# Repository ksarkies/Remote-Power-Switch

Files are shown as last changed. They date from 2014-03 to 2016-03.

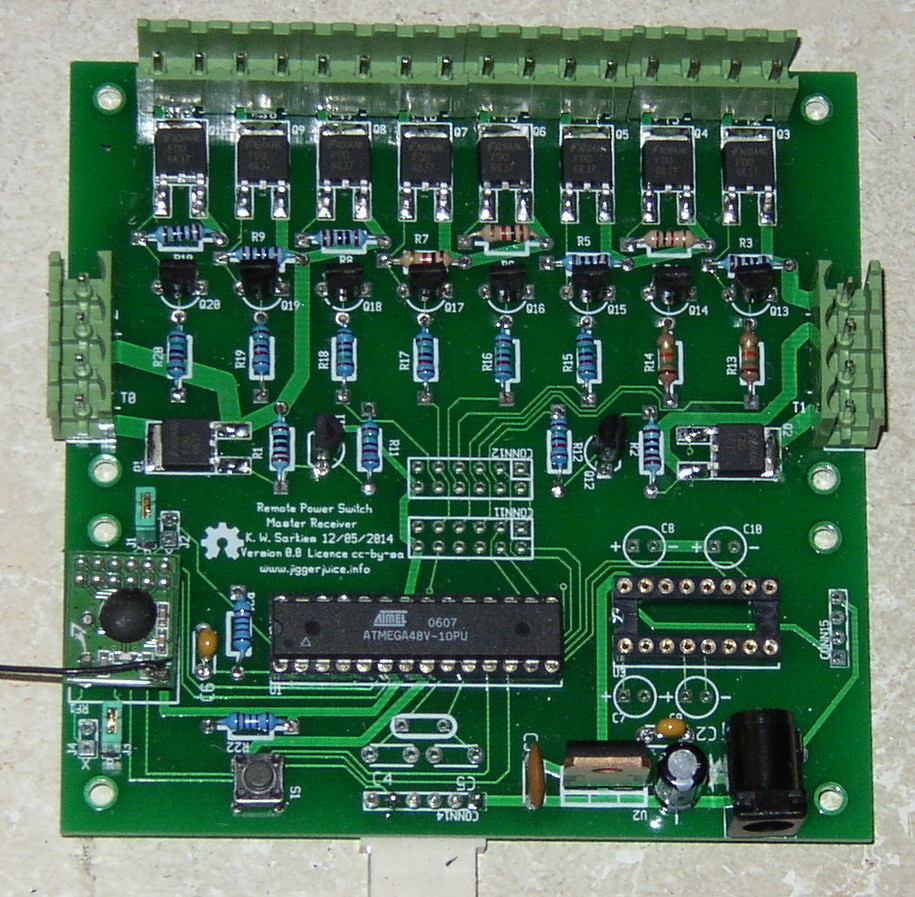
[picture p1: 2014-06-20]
gEDA-master-receiver/master-receiver-photo.jpg

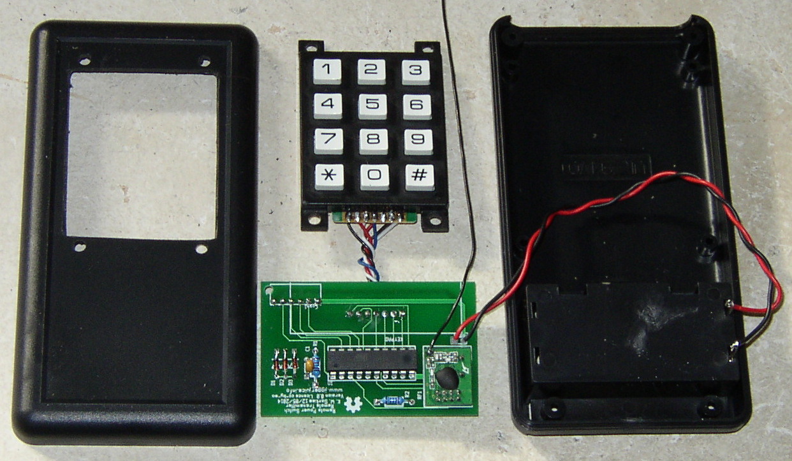
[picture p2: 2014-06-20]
gEDA-remote-transmitter/remote-transmitter-photo.jpg

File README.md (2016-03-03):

Remote Power Switch
-------------------

This small project makes use of Hope RF modules sold by Futurlec and others
to enable remote switching of low voltage power.

(NOTE: These modules seem to be unobtainable. However similar modules such as
the ALPHA-TRX433S, a rebadged version of the 433MHz RFM12B, are available.
The project needs to be redesigned for these and has not been further
developed.)

The background is a 12V power distribution system in a building which is
isolated from the grid and uses solar batteries for all power. The low voltage
used in the system requires care to be taken in regard to losses, so it was
decided to avoid using wall switches which would require additional cable length
with its attendant loss.

A small board uses an RFM02 transmitter module in a hand unit with an Atmel
ATTiny2313. A receiver board using an RFM01 receiver module is mounted at the
power distribution box. While the RF modules supposedly used SPI, the RFM02
modules actually uses a modification of this, meaning that an inbuilt SPI
peripheral on the microcontroller cannot be used. The transmission system is
FM in the 433MHz band.

The system operates by transmitting a single ASCII number continuously when a
button is pressed on the remote unit. The receiver will collect all received
symbols and uses a set of "bins", one for each possible symbol, to hold a
count of the number of each symbol received. A decision is made after 10 symbols
have arrived by selecting the symbol with the most counts. No more decisions are
made until a preset delay has elapsed following the last reception.

More information is available on [Jiggerjuice](www.jiggerjuice.info/electronics/projects/remotecontrol/remote-control-switch.html).

The receiver board is designed to take RFM12 transceiver modules so that the
hardware can double as a serial communications system between two base stations.

More information is available on [Jiggerjuice](www.jiggerjuice.info/electronics/projects/remotecontrol/serial-link-transceiver.html).

K. Sarkies
4 January 2015

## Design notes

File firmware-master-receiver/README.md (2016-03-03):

Remote Power Switch Rx Firmware
-------------------------------

The unit enters sleep mode until woken by a received character or the timer.
It collects all received characters, filters out invalid characters, and counts
instances of each valid character. After 10 valid characters have been received,
the character with the highest count is considered to be the correct
transmission. This is a form of maximum likelihood estimator.

The ATMega48 AVR microcontroller must have 8MHz internal RC oscillator and
no other fuse bits set except for the serial programming enable.

More information has been posted on [Jiggerjuice](www.jiggerjuice.info/electronics/projects/remotecontrol/remote-control-switch.html).

K. Sarkies

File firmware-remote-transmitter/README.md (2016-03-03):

Remote Power Switch Tx Firmware
-------------------------------

The unit enters sleep mode until a keyboard interrupt occurs. It then scans
the keys to determine which one was pressed. Debounce is performed, then the
digit is transmitted via the RFM02 module. This process continues as long
as the key is pressed.

The clock of the ATTiny2313 must be set to internal calibrated 8MHz. The clock
divide by 8 must be unset.

More information has been posted on [Jiggerjuice](www.jiggerjuice.info/electronics/projects/remotecontrol/remote-control-switch.html).

K. Sarkies

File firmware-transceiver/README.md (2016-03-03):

Remote Power Switch Transceiver Firmware
----------------------------------------

The Transceiver unit provides a serial link with input and output at RS232 or
logic levels.

The serial bit rate at both ends of the link needs to be the same as that set in
the firmware. This can be changed by recompiling the firmware. The transceiver
can handle bursts up to the length of the serial buffers. These are made larger
for AVRs with larger RAM.

The throughput of the unit is restricted by buffer size and AVR speed. A large
amount of serial data sent in a burst can result in loss.

The AVR C library rfm12lib by Hansinator, Tixiv and Soeren provides the software
support for the RFM12 modules. The interrupt driven UART library developed by
Peter Fleury is also used.

More information is found on [Jiggerjuice](www.jiggerjuice.info/electronics/projects/remotecontrol/serial-link-transceiver.html).

The ATMega48 series is used. The USART buffer sizes are:
ATMega48    128
ATMega88    256
ATMega168   256
ATMega328   1024

K. Sarkies
20 April 2015

TODO: Add sleep modes for AVR and RFM12 after 10 seconds inactivity. Wake on
      USART and INT0.

TODO: Attempts were made to improve throughput, without success, for use with
the Battery Management System. A request for a long directory listing results
in the latter losing characters. Sending the BMS general data at low priority
and the directory listing at high priority made no difference. The most
likely explanation is the limited buffering available in the transceiver AVR.

Some improvements would be:
- Add USART flow control.
- Change the transceiver SCP interactions to hardware rather than software.

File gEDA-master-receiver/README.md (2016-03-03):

Remote Power Switch Rx PCB
--------------------------

This board has a dual purpose; serving as a receiver for the power switch and as
an RF to serial converter. The board is designed to allow cutting to separate
the microcontroller and the switch parts. Provision for a ribbon cable
connection between the two is given so that boards may be interchanged with
different types. This is compatible with the ET-REL8BRD 8 relay board, and
possibly others. It uses an Atmel microcontroller and a RFM01 Hope RF 433MHz FM
receiver. The alternate configuration takes an RFM12 transceiver with different
jumper settings. The RFM01 Receiver configuration uses jumpers labelled R, while
the RFM12 Transceiver uses configuration jumpers labelled X.

The switches are P-type MOSFETs with low speed BJT-resistor drivers for
simplicity. The microcontroller is a low cost ATMega48 or pin compatible
ATMEL device with provision for a crystal oscillator if needed. The serial
interface is provided by a MAX232 RS-232 driver, although the serial interface
could be simple logic level if desired by omitting the MAX232 and jumpering
between its input and output pins. The serial connector is a SIL header
compatible with the ET series of boards. An SPI programming connector is also
provided in a form compatible with other projects. The vertical version of this
(or the right angle version mounted underneath) must be used.

More information has been posted on [Jiggerjuice](www.jiggerjuice.info/electronics/projects/remotecontrol/remote-control-switch.html).

K. Sarkies

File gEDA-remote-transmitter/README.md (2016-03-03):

Remote Power Switch Tx PCB
--------------------------

This board is designed to fit into a 65mm by 130mm hand case, purchased from
Jaycar, with a 12 digit keypad. It has an Atmel microcontroller in sleep mode
that is woken up when a keypress is activated. An RFM02 Hope RF 433MHz
transmitter unit is also in sleep mode until needed.

The keypad is of unknown manufacturer, supplied by Futurlec. It has a 7 pin
connector underneath, below the top row of buttons. The board will 
need to be redesigned to suit other keypads, taking care about physical
mounting. This keypad can be mounted underneath the board and facing so that
the board partly covers it, or ir could be mounted on top of the board facing
the opposite direction if it is mounted high enough for other components to be
mounted underneath it. The right-angle SPI connector can be mounted on top of
the board under the keypad, or underneath facing in the opposite direction.
Space constraints require the RF board to sit partly underneath the keypad.

The aerial for the RF board needs to be 173mm which is longer than the case. To
provide an efficient aerial it is made up of a 120mm length of wire with 6
turns wound over a 0.25W resistor (acting purely as a former) to make a bottom
loaded quarter wave aerial.

The row and column ports are set with the rows having high-level pullup and the
columns set to zero. A connection between any row and column will then result
in the interrupt line being pulled low via the diode network.

The prototype units have survived for over 12 months without a change of
batteries.

More information has been posted on [Jiggerjuice](www.jiggerjuice.info/electronics/projects/remotecontrol/remote-control-switch.html).

K. Sarkies
30 May 2014

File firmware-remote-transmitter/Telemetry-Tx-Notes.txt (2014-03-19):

    /* Configuration Setting: 433MHz, CLK 5MHz, 11,5pf Kapaz., +/-60kHz */
    sendbyte(0b10001110);    sendbyte(0b01100000); 
0x8E60
    /* Frequency Setting: eingestellter Kanal*/
    uc_frequ[1]|=0b10100000;
0xA0xx
    /* Output Power Command: Max Power */
    sendbyte(0b10110000);
0xB0
    /* Data Rate Command: 2400 bit/s */
    sendbyte(0b11001000);    sendbyte(0b10001111); 
0xC88F
    /* Low Batt + Sync Command: enable Sync Circuit */
    sendbyte(0b11000010);    sendbyte(0b00100000); 
0xC220
    /* PLL Setting Command: 0xD240 up to 19,2kbit/s*/
    sendbyte(0b11010010);    sendbyte(0b01000000); 
0xD240
    /* Power Managment Command= Enable Clock; disable Synthesizer; disable pow. Ampl. */
    sendbyte(0b11000000);    sendbyte(0b00100000); 
0xC020

Main program checks for new values, sends them, and reinitializes the entire Tx chain if the transmission takes too long to complete.

    /* Power Managment Command= Enable Clock; enable Synthesizer; enable pow. Ampl. */
    sendbyte(0b11000000);    sendbyte(0b00111000); 
0xC034
    /*Sender Start Byte senden*/
    sendbyte(0b11000110);
0xC6

He appears to start transmission immediately after turning on the Synthesizer, which normally needs 250uS. The clock is already on.

Transmission of data is sent one bit at a time and paced by interrupt (on INT0 from nIRQ presumably).

    /* Power Managment Command= Enable Clock; disable Synthesizer; disable pow. Ampl. */
    sendbyte(0b11000000);    sendbyte(0b00100000); 
0xC020
--------------------------------------------------------------------------------------------------------------------------
Rx
    /* Frequency Setting: 434MHz (je nach Kanal) */
    uc_frequ[1]|=0b10100000;
0xA015
    
    /* Configuration Setting: 433MHz, CLK on, 11,5pf Kapaz., 67kHz */
    sendbyte(0b10001001);    sendbyte(0b01101100); 
0x8A6C
    
    /* Low Batt Clock Divider Command: clock 5MHz */
    sendbyte(0b11000010);    sendbyte(0b11000000); 
0xC2C0
    
    /* Receiver Setting Command: VDI= Digital RSSI Out, -103dB, receiver disabled */
    sendbyte(0b11000000);    sendbyte(0b10000000);
0xC080
    
    /* Receiver Setting Command: VDI= Digital RSSI Out, -103dB receiver enabled */
    sendbyte(0b11000000);    sendbyte(0b10000001);
0xC081
       
    /* FIFO Command: Enable FIFO, IT level=8, Sync. Patt + VDI, stop FIFO  */
    sendbyte(0b11001110);    sendbyte(0b10001001);
0xCE89
    
    /* FIFO Command: Enable FIFO, IT level=8, Sync. Patt + VDI, start FIFO  */
    sendbyte(0b11001110);    sendbyte(0b10001011);
0xCE8B
    
    /* Data Filter Command:  */
    sendbyte(0b11000100);    sendbyte(0b10101100); 
0xC4AC    
    
    /* Data Rate Command: 2400 bit/s */
    sendbyte(0b11001000);    sendbyte(0b10010001);
0xC891    
    
    /* AFC Command: Enable AFC, +3/-4, offset at VDI high */
    sendbyte(0b11000110);    sendbyte(0b10111111); 
0xC6BF

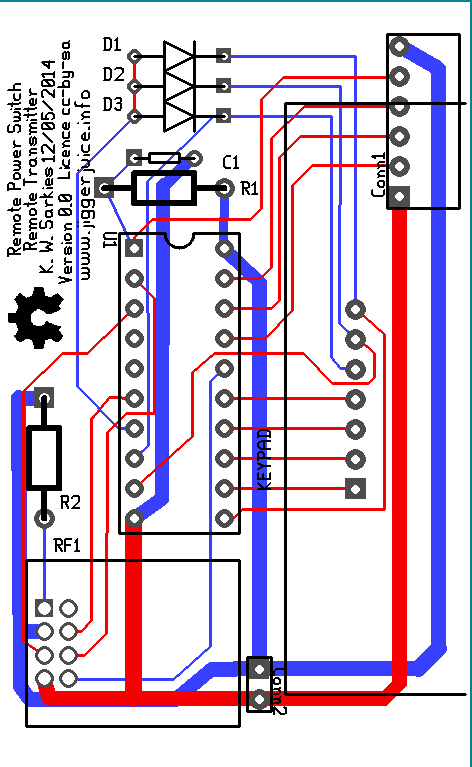
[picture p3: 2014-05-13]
gEDA-remote-transmitter/remote-transmitter-pcb-v1.png

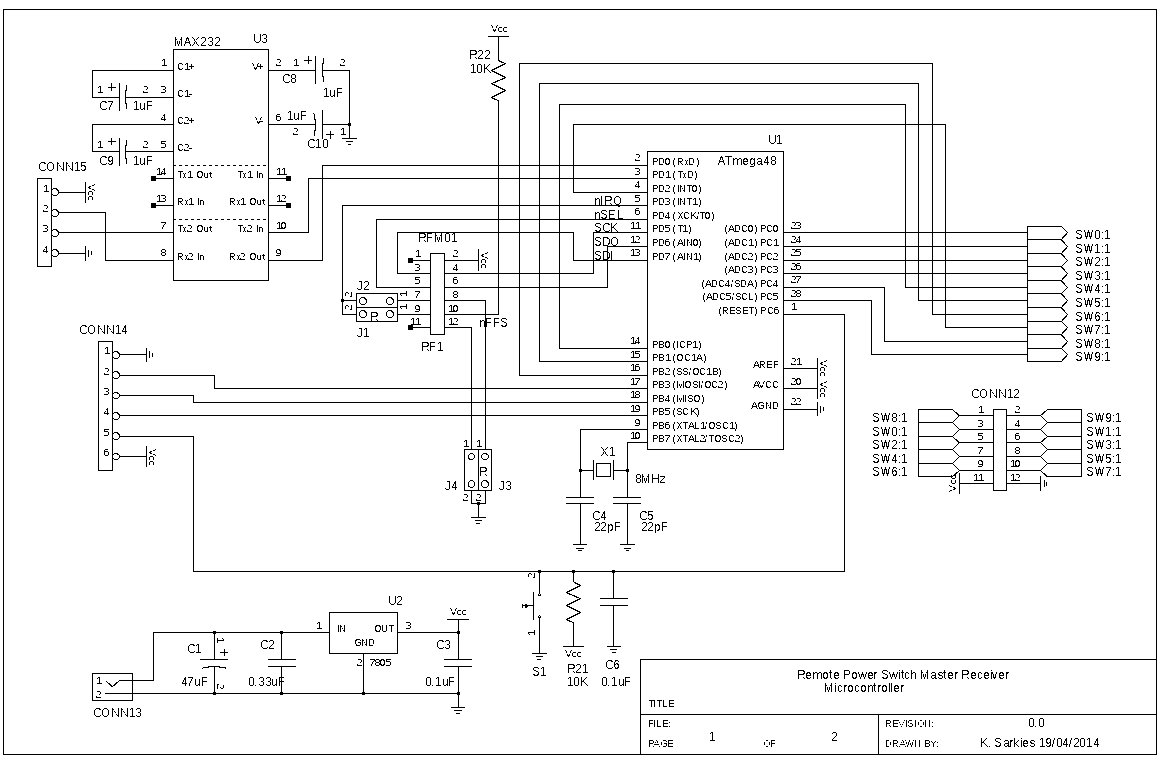
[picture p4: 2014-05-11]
gEDA-master-receiver/master-receiver-mc.png

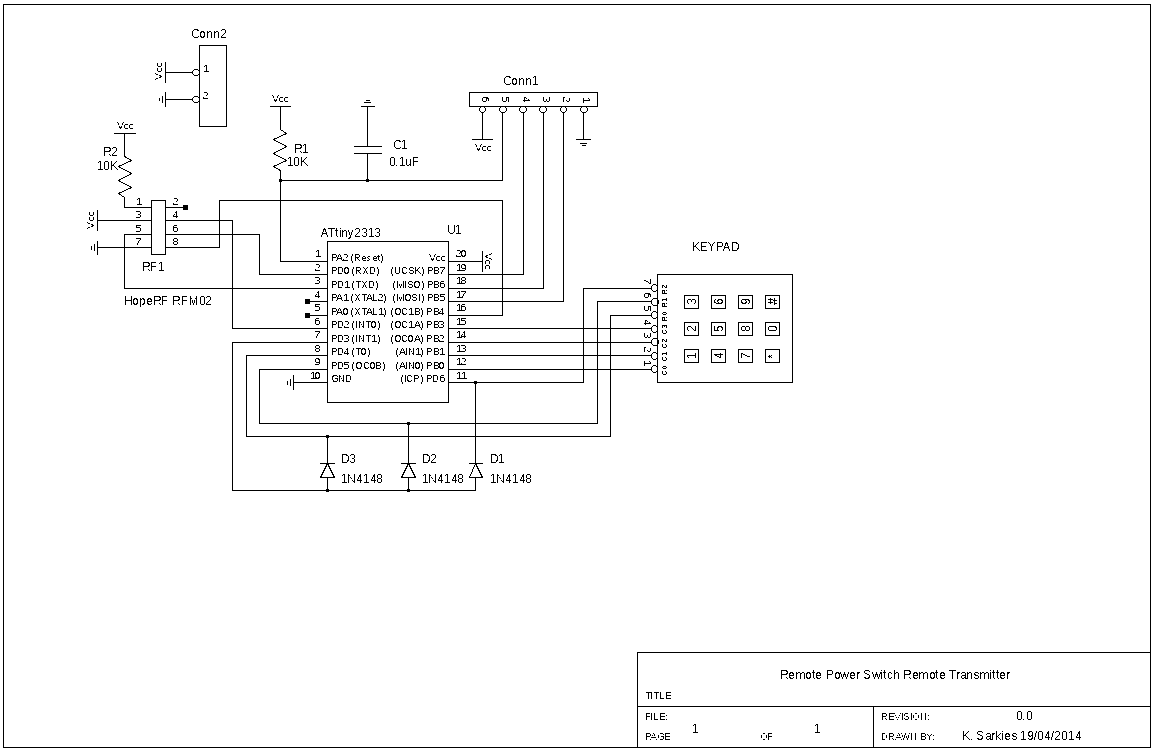
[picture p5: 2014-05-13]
gEDA-remote-transmitter/remote-transmitter.png

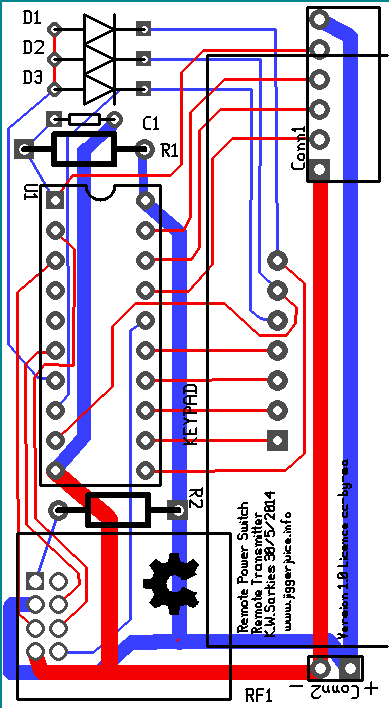
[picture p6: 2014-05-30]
gEDA-remote-transmitter/remote-transmitter-pcb.png

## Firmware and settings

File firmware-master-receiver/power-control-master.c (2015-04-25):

/**
@mainpage Power Control Project Master Unit
@version 0.0.0
@author Ken Sarkies (www.jiggerjuice.net)
@date 25 April 2015
@brief Code for a Master Power Switch unit

*** This sets the sleep mode, and requires the 8-bit timer 0 to generate
*** a timing tick.

This is a project to control power remotely using a wireless connection
between remote control units and a master switch unit. The master switch
board will interface to an ET-REL8 relay board using a 10 pin connector.
Each relay is activated by a separate port pin. It also interfaces to a
Hope RFM01 433MHz receiver module.

In principle the Master Power Switch units can be used for a wide range of
purposes as they simply receive command bytes over a serial link interface.
The interface used is the SPI interface to match the radio receiver module
RFM01. Other interfaces could simply be substituted.

The protocol used needs to match the sync pattern of the RF receiver:

AA AA AA 2D D4 ...

@note
Software: AVR-GCC 3.4.5
@note
Target:   Any AVR with sufficient output ports and a timer
@note
Tested:   ATMega48 at 8MHz internal clock.
 */
/***************************************************************************
 *   Copyright (C) 2011 by Ken Sarkies                                     *
 *   ksarkies@internode.on.net                                             *
 *                                                                         *
 *   This file is part of Power Controller                                 *
 *                                                                         *
 *   This is free software; you can redistribute it and/or modify          *
 *   it under the terms of the GNU General Public License as published by  *
 *   the Free Software Foundation; either version 2 of the License, or     *
 *   (at your option) any later version.                                   *
 *                                                                         *
 *   This software is distributed in the hope that it will be useful,      *
 *   but WITHOUT ANY WARRANTY; without even the implied warranty of        *
 *   MERCHANTABILITY or FITNESS FOR A PARTICULAR PURPOSE.  See the         *
 *   GNU General Public License for more details.                          *
 *                                                                         *
 *   You should have received a copy of the GNU General Public License     *
 *   along with the software. If not, write to the:                        *
 *   Free Software Foundation, Inc.,                                       *
 *   51 Franklin St, Fifth Floor, Boston, MA  02110-1301  USA.             *
 ***************************************************************************/

#include <inttypes.h>
#include <avr/sfr_defs.h>
#include <avr/wdt.h>
#include <avr/io.h>
#include <avr/interrupt.h>
#include <avr/sleep.h>
#include <util/delay.h>
#include "power-control-master.h"
#include "../libs-master-receiver/power-control-atmega48.h"
#include "../libs-master-receiver/rfm01.h"
/* Need to include source file here to access defines referred to above */
#include "../libs-master-receiver/rfm01.c"

/** Convenience macros (we don't use them all) */
#define TRUE 1
#define FALSE 0

#define inb(sfr) _SFR_BYTE(sfr)
#define inw(sfr) _SFR_WORD(sfr)
#define outb(sfr, val) (_SFR_BYTE(sfr) = (val))
#define outw(sfr, val) (_SFR_WORD(sfr) = (val))
#define cbi(sfr, bit) (_SFR_BYTE(sfr) &= ~_BV(bit))
#define sbi(sfr, bit) (_SFR_BYTE(sfr) |= _BV(bit))
#define high(x) ((uint8_t) (x >> 8) & 0xFF)
#define low(x) ((uint8_t) (x & 0xFF))

/*****************************************************************************/
/* Global Variables */

/** Set of 12 byte bins to count data received values. These will be used to
determine the median data value after a number of valid receives. */
uint8_t dataCount[12];
/** Real Time Clock Global Variable, ticks are 30.5 per second */
uint32_t timeValue;

/*****************************************************************************/
/* Local Prototypes */

void hardwareInit(void);
void wdtInit(void);
void snooze(void);
void setSwitch(uint8_t bestData);
void clearSwitches(void);
void resetTimer(void);
/*****************************************************************************/
/** @brief Main Program */

int main(void)
{
    hardwareInit();                 /* Initialize the processor specific hardware */
    resetTimer();                   /* Configure the timer */
    timeValue = 0;                  /* reset timer */
    initSPI();
    receiverConfigure();            /* Initialize the receiver */
    uint8_t data = 0;
    uint8_t invalidData = 0;
    uint8_t validData = 0;
    uint8_t locked = FALSE;
    for (uint8_t bin=0; bin < 12; bin++) dataCount[bin] = 0;

/** The main loop will check for symbols received. This is tested for
validity and counted in bins to determine the median value as a best
estimate. Then the data is interpreted to toggle one of a number of ports
or perform other actions. The system is then locked to prevent any further
interpretations until a period of 2 seconds has elapsed following the last
valid received symbol. */

    for(;;)
    {
/** The processor sleeps until woken by a received byte or a timer tick */
        snooze();
	    uint16_t receiverStatus = readDataByte();
/** The MSB of the status word is tested as FFIT. */
        if ((receiverStatus & 0x8000) != 0)    /* Check if something received */
        {
/** If nothing has been received for 2 seconds, release and clear the system to
allow other control commands to be activated. */
            if (timeValue > 61)
            {
                locked = FALSE;
                invalidData = 0;
                validData = 0;
                for (uint8_t bin=0; bin < 12; bin++) dataCount[bin] = 0;
            }
            resetTimer();
            timeValue = 0;                  /* reset timer */
            data = low(receiverStatus);
            resetFIFO();
/** When data is received, check if it is valid and increment its bin */
            if ((data < 12) && !locked)
            {
                dataCount[data]++;
                validData++;
            }
            else invalidData++;
/** Wait for 10 valid received data and then check the bins */
            if (validData == 10)
            {
                locked = TRUE;              /* prevent more recognitions */
                validData = 0;              /* prevent returning here while locked */
/** Look through bins and find the location of the peak (will return first equal peak) */
                uint8_t maxData = 0;
                uint8_t bestData = 0;
                for (uint8_t i=0; i<12; i++)
                {
                    if (dataCount[i] > maxData)
                    {
                        maxData = dataCount[i];
                        bestData = i;
                    }
                }
/** With the estimated data value, set the appropriate port. Toggle the
existing value of the port. */
                if (bestData < 10) setSwitch(bestData);
/** Use the remaining four symbols for general controls */
/* Turn off all ports */
                else if (bestData == 11) clearSwitches();
            }
        }
    }
}

/****************************************************************************/
/** @brief Initialize the hardware.
*/
void hardwareInit(void)
{
/** Power down Timers 0 and 1, TWI, SPI, ADC and USART */
    outb(PRR,0xBF);
/** We use Interrupt 1 with level triggering for power save mode */
    sbi(EIMSK,INT1);                /* Enable Interrupt 1 */
    cbi(EICRA,ISC11);               /* Set level trigger on interrupt 1 */
    cbi(EICRA,ISC10);
/** Set control ports as outputs */
    outb(DDRC,inb(DDRC) | 0x3F);
    outb(DDRB,inb(DDRB) | 0x07);
    outb(DDRD,inb(DDRD) | 0x04);
    sei();                          /* Enable global interrupts */
}

/****************************************************************************/
/** @brief   Initialise Timer 2

This function will initialise the timer with the mode of operation and the
clock rate to be used.
*/

void resetTimer(void)
{
/** Set timer to FCPU/1024 which is about 30.5 overflows per second for 8MHz. */
    outb(TIMER_CONT_REG,((inb(TIMER_CONT_REG) & 0xF8) | 5));
    outb(TCOUNT,0);              /* Clear the register */
    sbi(TIMER_FLAG_REG, TOV);    /* Force clear the overflow interrupt flag */
    sbi(TIMER_MASK_REG, TOIE);   /* Enable the overflow interrupt */
}

/****************************************************************************/
/** @brief Initialize the watchdog timer to interrupt on maximum delay

*/
void wdtInit(void)
{
/* Initialize the Watchdog timer to interrupt. */
/* IMPORTANT: Disable the "WDT Always On" fuse so that WDT can be turned off. */
    wdt_disable();     /* watchdog timer turn off ready for setup. */
    outb(WDTCR,0);
/* Set the WDT with WDE clear, interrupts enabled, interrupt mode set, and
maximum timeout 8 seconds to give continuous interrupt mode. */
    sei();
}

/****************************************************************************/
/** @brief Send processor to sleep and manage interrupts.

This function is called at the beginning of every processing loop. The INT1
is enabled before sleeping, and disabled after wakeup.
*/
void snooze(void)
{
    sei();                              /* Enable global interrupts */
    sbi(EIMSK,INT1);                    /* Enable Interrupt 1 */
    set_sleep_mode(SLEEP_MODE_PWR_SAVE);
    sleep_mode();                       /* Enter sleep mode */
    cbi(EIMSK,INT1);                    /* Disable Interrupt 1 */
}

/****************************************************************************/
/** @brief Manage the power switching.

Adapt the switches 0-9 to the actual microcontroller port outputs.

@param[in] uint8_t bestData. The number of the switch to toggle.
*/
void setSwitch(uint8_t bestData)
{
    uint16_t bestBit = (1 << bestData);
/* The lower 4 bits of PORTC are the first four ports */
    if (bestData < 4) outb(PORTC,inb(PORTC) ^ bestBit);
/* The lower 3 bits of PORTB are the next three ports */
    else if (bestData < 7) outb(PORTB,inb(PORTB) ^ (bestBit >> 4));
/* Bit 2 of PORTD is the eighth port */
    else if (bestData == 7) outb(PORTD,inb(PORTD) ^ 4);
/* Bits 4,5 of PORTC are the ninth and tenth ports */
    else if (bestData < 10) outb(PORTC,inb(PORTC) ^ (bestBit >> 4));
}

/****************************************************************************/
/** @brief Turn off all power switching.
*/
void clearSwitches(void)
{
    outb(PORTC,(inb(PORTC) & ~0x3F));
    outb(PORTB,(inb(PORTB) & ~0x07));
    outb(PORTD,(inb(PORTD) & ~0x04));
}
/****************************************************************************/
/** @brief Interrupt on nIRQ from Receiver.

This ISR does nothing except to allow the processor to wakeup.
*/
ISR(REC_INTERRUPT)
{
}

/****************************************************************************/
/** @brief Interrupt on RTC timer overflow

This ISR simply updates the RTC.
*/
ISR(TIMER_INTERRUPT)
{
  timeValue++;
}

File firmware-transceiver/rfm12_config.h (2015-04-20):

/**** RFM 12 library for Atmel AVR Microcontrollers *******
 * 
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
 * @author Peter Fuhrmann, Hans-Gert Dahmen, Soeren Heisrath
 */

#ifndef _RFM12LIB_H_
#define _RFM12LIB_H_

/******************************************************
 *                                                    *
 *           C O N F I G U R A T I O N                *
 *                                                    *
 ******************************************************/

/*
	Connect the RFM12 to the AVR as follows:

	RFM12           | AVR
	----------------+------------
	SDO             | MISO
	nIRQ            | INT0
	FSK/DATA/nFFS   | VCC
	DCLK/CFIL/FFIT  |  -
	CLK             |  -
	nRES            |  -
	GND             | GND
	ANT             |  -
	VDD             | VCC
	GND             | GND
	nINT/VDI        | -
	SDI             | MOSI
	SCK             | SCK
	nSEL            | Slave select pin defined below
*/


/************************
 * PIN DEFINITIONS
 */

/*Pin that the RFM12's slave select is connected to */
#define DDR_SS DDRD
#define PORT_SS PORTD
#define BIT_SS 4

/* Using Software SPI */
/*SPI MOSI port */
#define DDR_MOSI DDRD
#define PORT_MOSI PORTD

/*SPI MISO port */
#define DDR_MISO DDRD
#define PIN_MISO PIND

/*SPI SCK port */
#define DDR_SCK DDRD
#define PORT_SCK PORTD

/*SPI SS port */
#define DDR_SPI_SS DDRD
#define PORT_SPI_SS PORTD 

/*SPI pin numbers on their respective ports */
#define BIT_MOSI 7
#define BIT_MISO 6
#define BIT_SCK  5
#define BIT_SPI_SS 4

/************************
 * RFM12 CONFIGURATION OPTIONS
 */

//baseband of the module (either RFM12_BAND_433, RFM12_BAND_868 or RFM12_BAND_912)
#define RFM12_BASEBAND RFM12_BAND_433

//center frequency to use (+-125kHz FSK frequency shift)
#define FREQ 433175000UL

//use this for datarates >= 2700 Baud
#define DATARATE_VALUE RFM12_DATARATE_CALC_HIGH(38400.0)

//use this for 340 Baud < datarate < 2700 Baud
//#define DATARATE_VALUE RFM12_DATARATE_CALC_LOW(1200.0)

//TX BUFFER SIZE
#ifndef RFM12_TX_BUFFER_SIZE
#define RFM12_TX_BUFFER_SIZE 30
#endif

//RX BUFFER SIZE (there are going to be 2 Buffers of this size for double_buffering)
#ifndef RFM12_RX_BUFFER_SIZE
#define RFM12_RX_BUFFER_SIZE 30
#endif


/************************
 * INTERRUPT VECTOR
 * set the name for the interrupt vector here
 */
 
//the interrupt vector
#define RFM12_INT_VECT (INT1_vect)

//the interrupt mask register
#define RFM12_INT_MSK EIMSK

//the interrupt bit in the mask register
#define RFM12_INT_BIT (INT1)

//the interrupt flag register
#define RFM12_INT_FLAG EIFR

//the interrupt bit in the flag register
#define RFM12_FLAG_BIT (INTF1)

//setup the interrupt to trigger on negative edge
#define RFM12_INT_SETUP()   EICRA |= (1<<ISC11)


/************************
 * FEATURE CONFIGURATION
 */

#define RFM12_LIVECTRL 0
#define RFM12_NORETURNS 0
#define RFM12_NOCOLLISIONDETECTION 0
#define RFM12_TRANSMIT_ONLY 0
#define RFM12_SPI_SOFTWARE 1
#define RFM12_USE_POLLING 0
#define RFM12_RECEIVE_ASK 0
#define RFM12_TRANSMIT_ASK 0
#define RFM12_USE_WAKEUP_TIMER 0
#define RFM12_LOW_POWER 0


/************************
 * UART DEBUGGING
 * en- or disable debugging via uart.
 */
 
#define RFM12_UART_DEBUG 0

#endif

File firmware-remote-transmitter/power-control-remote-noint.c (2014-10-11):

/**
@mainpage Power Control Project Remote Unit on AVR
@version 0.0.0
@author Ken Sarkies (www.jiggerjuice.info)
@date 06/06/2011
@brief Test code for a Remote Power Switch unit on AVR

Based on code by:
 * (C) 2009 by Tomasz bla Fortuna <bla@thera.be>.
 * http://olek.tk/en/rfm12.php
 * License: GPLv3+ (See Docs/LICENSE)

This is a project to control power remotely using a wireless connection
between remote control units and a master switch unit.

In principle the remote control units can be used for a wide range of
purposes as they simply send keyboard command bytes from keypresses
over a serial link interface. The interface used is the SPI interface to
match the radio transmitter module Hope RFM02. Other interfaces could simply
be substituted.

The protocol used needs to match the sync pattern of the RF receiver, but
otherwise the packets will have the same structure as that for the acquisition
project. The sync pattern is:

AA AA AA 2D D4 ...

@note
Software: AVR-GCC 3.4.5
@note
Target:   Any AVR
@note
Tested:   ATMega48, ATTiny2313 at 8MHz internal clock.
 */
/***************************************************************************
 *   Copyright (C) 2010 by Ken Sarkies                                     *
 *   ksarkies@internode.on.net                                             *
 *                                                                         *
 *   This file is part of Power Controller                                 *
 *                                                                         *
 *   This is free software; you can redistribute it and/or modify          *
 *   it under the terms of the GNU General Public License as published by  *
 *   the Free Software Foundation; either version 2 of the License, or     *
 *   (at your option) any later version.                                   *
 *                                                                         *
 *   This software is distributed in the hope that it will be useful,      *
 *   but WITHOUT ANY WARRANTY; without even the implied warranty of        *
 *   MERCHANTABILITY or FITNESS FOR A PARTICULAR PURPOSE.  See the         *
 *   GNU General Public License for more details.                          *
 *                                                                         *
 *   You should have received a copy of the GNU General Public License     *
 *   along with the software. If not, write to the:                        *
 *   Free Software Foundation, Inc.,                                       *
 *   51 Franklin St, Fifth Floor, Boston, MA  02110-1301  USA.             *
 ***************************************************************************/

#define F_CPU               8000000

#include <inttypes.h>
#include <avr/sfr_defs.h>
#include <avr/wdt.h>
#include <avr/io.h>
#include <avr/interrupt.h>
#include <avr/sleep.h>
#include <util/delay.h>
#include "power-control-remote.h"
#if defined __AVR_ATmega48__
    #include "power-control-atmega48.h"
#elif defined __AVR_ATtiny2313__
    #include "power-control-attiny2313.h"
#else
    #error "Unsupported MPU"
#endif

/* Convenience macros (we don't use them all) */
#define TRUE 1
#define FALSE 0

#define inb(sfr) _SFR_BYTE(sfr)
#define inw(sfr) _SFR_WORD(sfr)
#define outb(sfr, val) (_SFR_BYTE(sfr) = (val))
#define outw(sfr, val) (_SFR_WORD(sfr) = (val))
#define cbi(sfr, bit) (_SFR_BYTE(sfr) &= ~_BV(bit))
#define sbi(sfr, bit) (_SFR_BYTE(sfr) |= _BV(bit))
#define high(x) ((uint8_t) (x >> 8) & 0xFF)
#define low(x) ((uint8_t) (x & 0xFF))

/* RFM02 Transmitter parameters specific for this application */

/* Band is 433MHz (POR 0 = 315MHz) */
#define RF_BAND                      1
/* clock output frequency (used for external clock to microcontroller etc) (POR 0 = 1MHz)
    0  1.00MHz
    1  1.25MHz
    2  1.66MHz
    3  2.00MHz
    4  2.50MHz
    5  3.33MHz
    6  5.00MHz
    7 10.00MHz */
#define CLOCK_FREQ_OUT               7
/* crystal load capacitance for the selected crystal,
    0000 is 8.5pF, increment in 0.5pF steps to maximum 15 (16pF) (POR 8 = 12.5pF). */
#define CRYSTAL_LOAD_CAPACITANCE     6
/* FSK Deviation is set (POR 0 = 30kHz)*/
#define DEVIATION                    0
/* This bit rate is close to 2400 baud */
//#define BIT_RATE                  0x8F
/* This bit rate is close to 9600 baud */
#define BIT_RATE                  0x23
/* Output power dB (POR 0 = 0dB) */
#define POWER                        0
/* Carrier frequency to exactly 433 MHz (POR 7D0 = 435MHz
Carrier frequency F, a 12 bit value between 96 and 3903 giving centre frequency
        f0 = 10MHz * C1 * (C2 + F/4000)
where C1/C2 are 1/43, 2/43 or 3/30 for bands 433, 868 and 915 respectively.
That is steps of 2.5kHz for the 433 and 868 RFM01_PM_SETTINGS bands,
and 7.5kHz for the 915kHz band. */
#define CARRIER                   1200
/* Low battery voltage setting (OR with disable timer calibration if needed)*/
#define TXSYN_LOWBATT             0x00
/* Power Management settings for the timer, battery and clock out. */
#define PM_SETTINGS_DEFAULT       0x00
/* Sleep clock turnoff delay (POR 0x10) */
#define SLEEP_DELAY               0x00
/* Wakeup period (POR 0) */
#define WAKEUP_EXPONENT           0x00
#define WAKEUP_DELAY              0x00

/* Complete command words */

#define CONFIGURATION   RFM02_CMD_CONFIG | ((RF_BAND & 0x03) << 11) | ((CLOCK_FREQ_OUT & 0x07) << 8) | ((CRYSTAL_LOAD_CAPACITANCE & 0x0F) << 4) | (DEVIATION & 0x0F)
#define POWERSET        RFM02_CMD_POWER_SET | (POWER & 0x07)
#define FREQUENCY       RFM02_CMD_FREQ | (CARRIER & 0xFFF)
#define PLL_MODE        RFM02_PLL_MODE1
#define WAKEUP          RFM02_CMD_WAKEUP | ((WAKEUP_EXPONENT & 0x1F) << 8) | (WAKEUP_DELAY & 0xFF)
#define POWERMANAGE     RFM02_CMD_POWERMGMT | (PM_SETTINGS_DEFAULT & 0xFF)
#define DATARATE        RFM02_CMD_RATE | (BIT_RATE & 0xFF)
#define TX_SYNC         RFM02_CMD_SYNC | RFM02_TXSYN_DISTIMCAL | RFM02_TXSYN_TXSYNC | (TXSYN_LOWBATT & 0x1F)
#define SLEEP           RFM02_CMD_SLEEP | SLEEP_DELAY

/* German developer settings
#define CONFIGURATION   0x8E60
#define POWERSET        0xB0
#define FREQUENCY       0xA4B0
#define PLL_MODE        0xD240
#define POWERMANAGE     0xC020
#define DATARATE        0xC88F
#define TX_SYNC         0xC220
*/
/*****************************************************************************/
/* Global Variables */

/****************************************************************************/
/** @brief Main Program */
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

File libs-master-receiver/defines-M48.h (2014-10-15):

/* AVR Defines for USART library

This file assigns registers, particular to an AVR type, to common constants.
It is valid for bootloader and application firmware.

I/O pin values for controlling the bootloader operation are given at the end.

Software: AVR-GCC 4.8.2
Target:   Any AVR with sufficient output ports and a timer
Tested:   ATMega48 series at 8MHz internal clock.
*/

/****************************************************************************
 *   Copyright (C) 2013 by Ken Sarkies ksarkies@internode.on.net            *
 *                                                                          *
 *   This file is part of Remote-Power-Switch                                  *
 *                                                                          *
 * Licensed under the Apache License, Version 2.0 (the "License");          *
 * you may not use this file except in compliance with the License.         *
 * You may obtain a copy of the License at                                  *
 *                                                                          *
 *     http://www.apache.org/licenses/LICENSE-2.0                           *
 *                                                                          *
 * Unless required by applicable law or agreed to in writing, software      *
 * distributed under the License is distributed on an "AS IS" BASIS,        *
 * WITHOUT WARRANTIES OR CONDITIONS OF ANY KIND, either express or implied. *
 * See the License for the specific language governing permissions and      *
 * limitations under the License.                                           *
 ***************************************************************************/

#ifndef _DEFINES_M48_H_
#define _DEFINES_M48_H_

#include	<avr/io.h>

/* Choose whether to use hardware flow control for serial comms. */
//#define USE_HARDWARE_FLOW

/* These are the defines for the selected device */
#define BAUD                115200

// Simple serial I/O (must define cpu frequency and baudrate before this include) */
#include <util/setbaud.h>

/* Convenience macros (we don't use them all) */
#define  _BV(bit) (1 << (bit))
#define  inb(sfr) _SFR_BYTE(sfr)
#define  inw(sfr) _SFR_WORD(sfr)
#define  outb(sfr, val) (_SFR_BYTE(sfr) = (val))
#define  outw(sfr, val) (_SFR_WORD(sfr) = (val))
#define  cbi(sfr, bit) (_SFR_BYTE(sfr) &= ~_BV(bit))
#define  sbi(sfr, bit) (_SFR_BYTE(sfr) |= _BV(bit))
#define  high(x) ((uint8_t) (x >> 8) & 0xFF)
#define  low(x) ((uint8_t) (x & 0xFF))

/* UART Error Definitions. */
#define NO_DATA                 0x01
#define BUFFER_OVERFLOW         0x02
#define OVERRUN_ERROR           0x04
#define FRAME_ERROR             0x08
#define STATE_MACHINE           0x10
#define CHECKSUM                0x11

/* definitions for UART control */
#define	BAUD_RATE_HIGH_REG	    UBRR0H
#define	BAUD_RATE_LOW_REG	    UBRR0L
#define	UART_CONTROL_REG	    UCSR0B
#define	UART_FORMAT_REG	        UCSR0C
#define FRAME_SIZE              UCSZ00
#define	ENABLE_TRANSMITTER_BIT	TXEN0
#define	ENABLE_RECEIVER_BIT	    RXEN0
#define	UART_STATUS_REG	        UCSR0A
#define	TRANSMIT_COMPLETE_BIT	TXC0
#define	RECEIVE_COMPLETE_BIT	RXC0
#define	UART_DATA_REG	        UDR0
#define DOUBLE_RATE             U2X0

/* UART Flow control ports */
#define UART_CTS_PORT           PIND
#define UART_CTS_PORT_DIR       DDRD
#define UART_CTS_PIN            2
#define UART_RTS_PORT           PORTD
#define UART_RTS_PORT_DIR       DDRD
#define UART_RTS_PIN            3

#endif

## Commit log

2014-03-19 Initial Commit of previously defined project. Some directories empty for now.
    [remote-power-switch-mc.sch]
2014-04-21 Addition of PCBs for the remote receiver and transmitter.
    [master-receiver-mc.sch, master-receiver-sw.sch, remote-power-switch-mc.sch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]
2014-04-23 Update PCB work, making the master receiver able to accept a transceiver with jumpers.
    [master-receiver-mc.sch]
2014-04-27 Partial completion of PCB for master switch. Correction of footprints and symbols to line up pins correctly. Change of schematic to move switch 1 to low priority group. This leaves 4 in the high prio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
    [master-receiver-mc.sch, master-receiver-sw.sch]
2014-04-27 Correction of symbols for the headers to ensure that the refdes ends in a number, otherwise PCB doesn't see them. Update gerbers.
    [remote-transmitter.sch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]
2014-04-27 More work on PCB layout for master
2014-04-28 Complete layout of PCB for master receiver. Mounting holes not placed.
    [master-receiver-mc.sch, master-receiver-sw.sch]
2014-04-29 Completion of Maaster Receiver board
    [master-receiver.back.gbl, master-receiver.backmask.gbs, master-receiver.backsilk.gbo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]
2014-04-30 Add logos and text to PCBs and regenerate gerbers and png
    [master-receiver.back.gbl, master-receiver.backmask.gbs, master-receiver.backsilk.gbo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]
2014-05-06 Gerber creation plus small adjustments mainly to add support holes to master receiver.
    [master-receiver.back.gbl, master-receiver.backmask.gbs, master-receiver.backsilk.gbo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]
2014-05-10 Update to master receiver to reorient RF board. Make power paths thicker and shorter. Set Terminals 0,1 for higher current.
    [master-receiver-mc.sch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]
2014-05-11 Minor changes to PCB, labelling, track with changes and drill hole for receiver barrel power connector.
    [master-receiver-mc.sch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]
2014-05-12 Tweaks ready for manufacture
    [master-receiver.back.gbl, master-receiver.backmask.gbs, master-receiver.backsilk.gbo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]
2014-05-13 Final versions for manufacture Change to keyboard footprint to correct outline.
    [remote-transmitter.sch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]
2014-05-30 Redo remote transmitter board to fit case Update footprints to increase drill size.
    [master-receiver-mc.sch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]
2014-06-06 Update power jack footprint and PCB for master receiver
2014-06-20 Bring back version 1 of PCB for remote transmitter Add photos
2014-07-06 Add small delay between end of transmission of a data byte and RFM02 power-off command. Sometimes the latter could be detected as a part of the data word.
2014-10-10 Add resistor to pull up nFFS pin on RFM12B. Will have no effect on RFM01 as the pin is grounded.
    [master-receiver-mc.sch]
2014-10-11 Minor refactoring of remote transmitter and receiver to move library type code out to a library directory and to make use of common defines and functions.
    The remote receiver has had the timer moved from 2 to 0 to match timer
    library pulled in from earlier work.
2014-10-11 Fix of transceiver example, now working. Added timer and transmit message when timer ticks over 1 second. This leaves the loop to run at full speed.
    [serial-link-transceiver.c]
2014-10-15 First attempt at interrupt driven serial I/O for ATMega88 Minor adjustments to other files for polled and non-interrupt driven serial.
2014-10-16 Change baudrate computation to use setbaud. Fix integer size bug
    [serial-link-transceiver.c]
2014-10-20 Bug using NARTOS - local variable carried over relinquish. Also added rfm12_tick to a wait loop to avoid infinite looping waiting for Tx
    [serial-link-transceiver.c]
2014-10-20 Update baudrate calculator to include some error and precision checks.
    [baud.h]
2014-10-31 Update PCB and Readme
2015-04-07 Fix bug in timeout waiting for another transmission. Changes to buffer sizes for larger AVIs.
    [serial-link-transceiver.c]
2015-04-08 Master firmware: Location of timer library changed.
2015-04-25 Master Receiver: Revert back to timer 2 defined in the code rather than externally.
    [power-control-atmega48.h, power-control-master.c]
